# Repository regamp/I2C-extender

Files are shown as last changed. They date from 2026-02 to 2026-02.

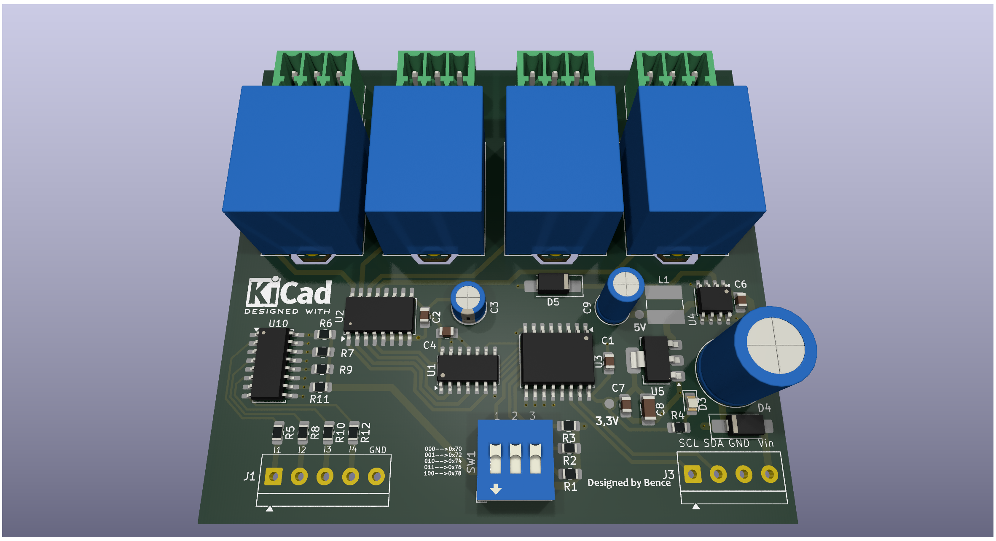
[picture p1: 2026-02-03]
Pictures/I2C_relay_module2.png

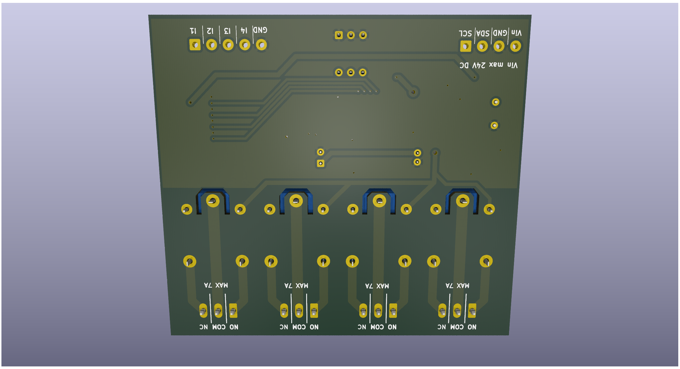
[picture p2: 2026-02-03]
Pictures/I2C_relay_module17.png

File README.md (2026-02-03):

# I2C-extender
I2C bus extender, 4 relay output and 4 input
KiCad 9 project
I2C_relay_module-1
ezgif com-animated-gif-maker
I2C_relay_module

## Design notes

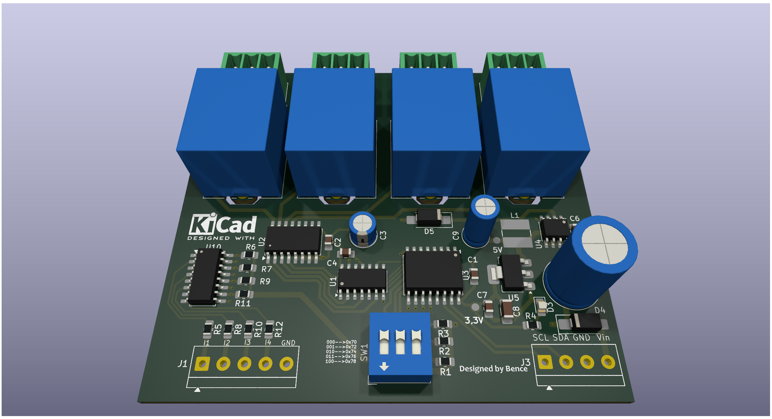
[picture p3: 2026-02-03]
Pictures/I2C_relay_module3.png

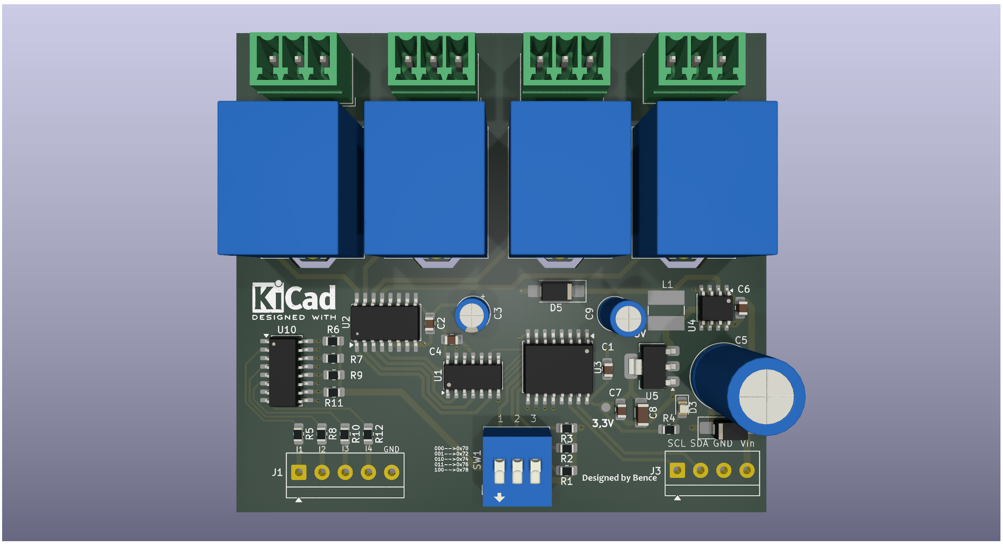
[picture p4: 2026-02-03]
Pictures/I2C_relay_module.png

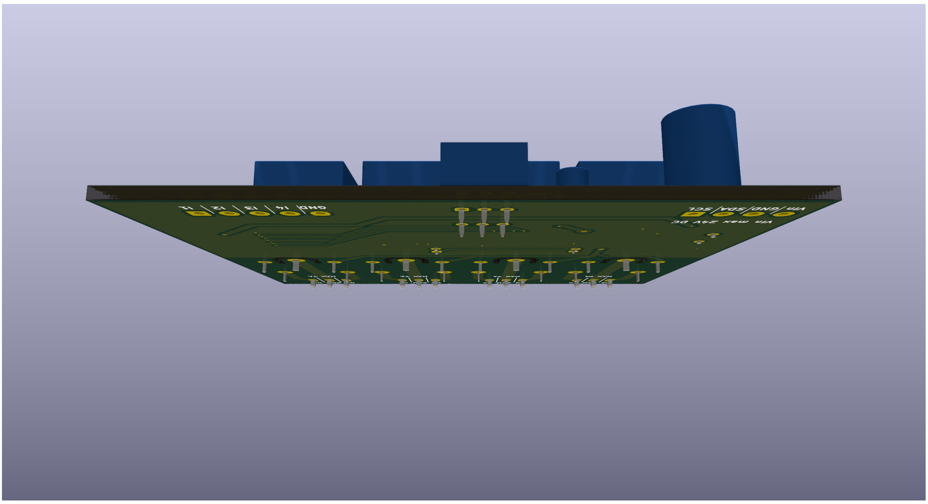
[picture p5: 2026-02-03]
Pictures/I2C_relay_module10.png

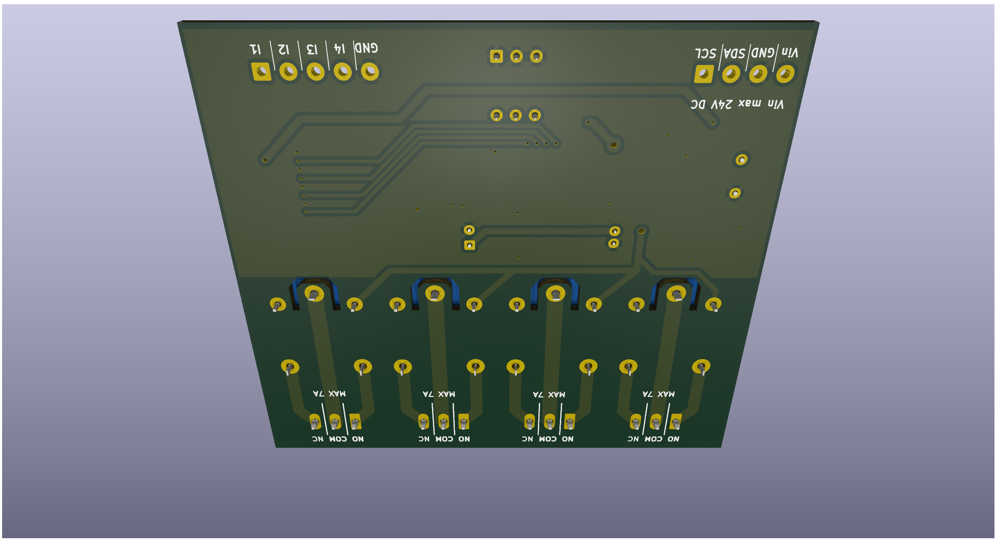
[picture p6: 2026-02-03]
Pictures/I2C_relay_module15.png

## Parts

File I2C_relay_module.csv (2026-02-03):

Id | Designator | Footprint | Quantity | Designation | Supplier and ref
1 | R1,R3,R2,R4 | R_0805_2012Metric_Pad1.20x1.40mm_HandSolder | 4 | 1k
2 | U3 | SOIC-16W_7.5x10.3mm_P1.27mm | 1 | PCF8574T
3 | K3,K4,K1,K2 | Relay_SPDT_SANYOU_SRD_Series_Form_C | 4 | SANYOU_SRD_Form_C
4 | C6,C4,C2,C1,C7 | C_0805_2012Metric_Pad1.18x1.45mm_HandSolder | 5 | 100n
5 | L1 | L_Ferrocore_DLG-0504 | 1 | 68uH
6 | C3 | CP_Radial_D5.0mm_P2.50mm | 1 | 100uF
7 | D3 | LED_0805_2012Metric_Pad1.15x1.40mm_HandSolder | 1 | LED
8 | J3 | TerminalBlock_MetzConnect_Type059_RT06304HBWC_1x04_P3.50mm_Horizontal | 1 | Screw_Terminal_01x04
9 | R6,R10,R12,R5,R9,R7,R8,R11 | R_0805_2012Metric_Pad1.20x1.40mm_HandSolder | 8 | 4k7
10 | D4 | D_SMA_Handsoldering | 1 | MRA4003T3G
11 | J2,J7,J5,J6 | PhoenixContact_MCV_1,5_3-G-3.5_1x03_P3.50mm_Vertical | 4 | Conn_01x03_Socket
12 | C8 | C_1206_3216Metric_Pad1.33x1.80mm_HandSolder | 1 | 10uF
13 | U10 | SOP-16_4.4x10.4mm_P1.27mm | 1 | ELQ3H4
14 | U2 | SOIC-16W_5.3x10.2mm_P1.27mm | 1 | ULN2003A
15 | D5 | D_SMA_Handsoldering | 1 | SS34
16 | J1 | TerminalBlock_MetzConnect_Type059_RT06305HBWC_1x05_P3.50mm_Horizontal | 1 | Screw_Terminal_01x05
17 | C5 | C_Radial_D10.0mm_H16.0mm_P5.00mm | 1 | 470uF
18 | U1 | SOIC-14_3.9x8.7mm_P1.27mm | 1 | 74HCT14
19 | U5 | SOT-223-3_TabPin2 | 1 | LM1117MP-3.3
20 | C9 | C_Radial_D5.0mm_H11.0mm_P2.00mm | 1 | 220uF
21 | U4 | SOIC-8_3.9x4.9mm_P1.27mm | 1 | XL1509-5.0
22 | SW1 | SW_DIP_SPSTx03_Slide_9.78x9.8mm_W7.62mm_P2.54mm | 1 | SW_DIP_x03

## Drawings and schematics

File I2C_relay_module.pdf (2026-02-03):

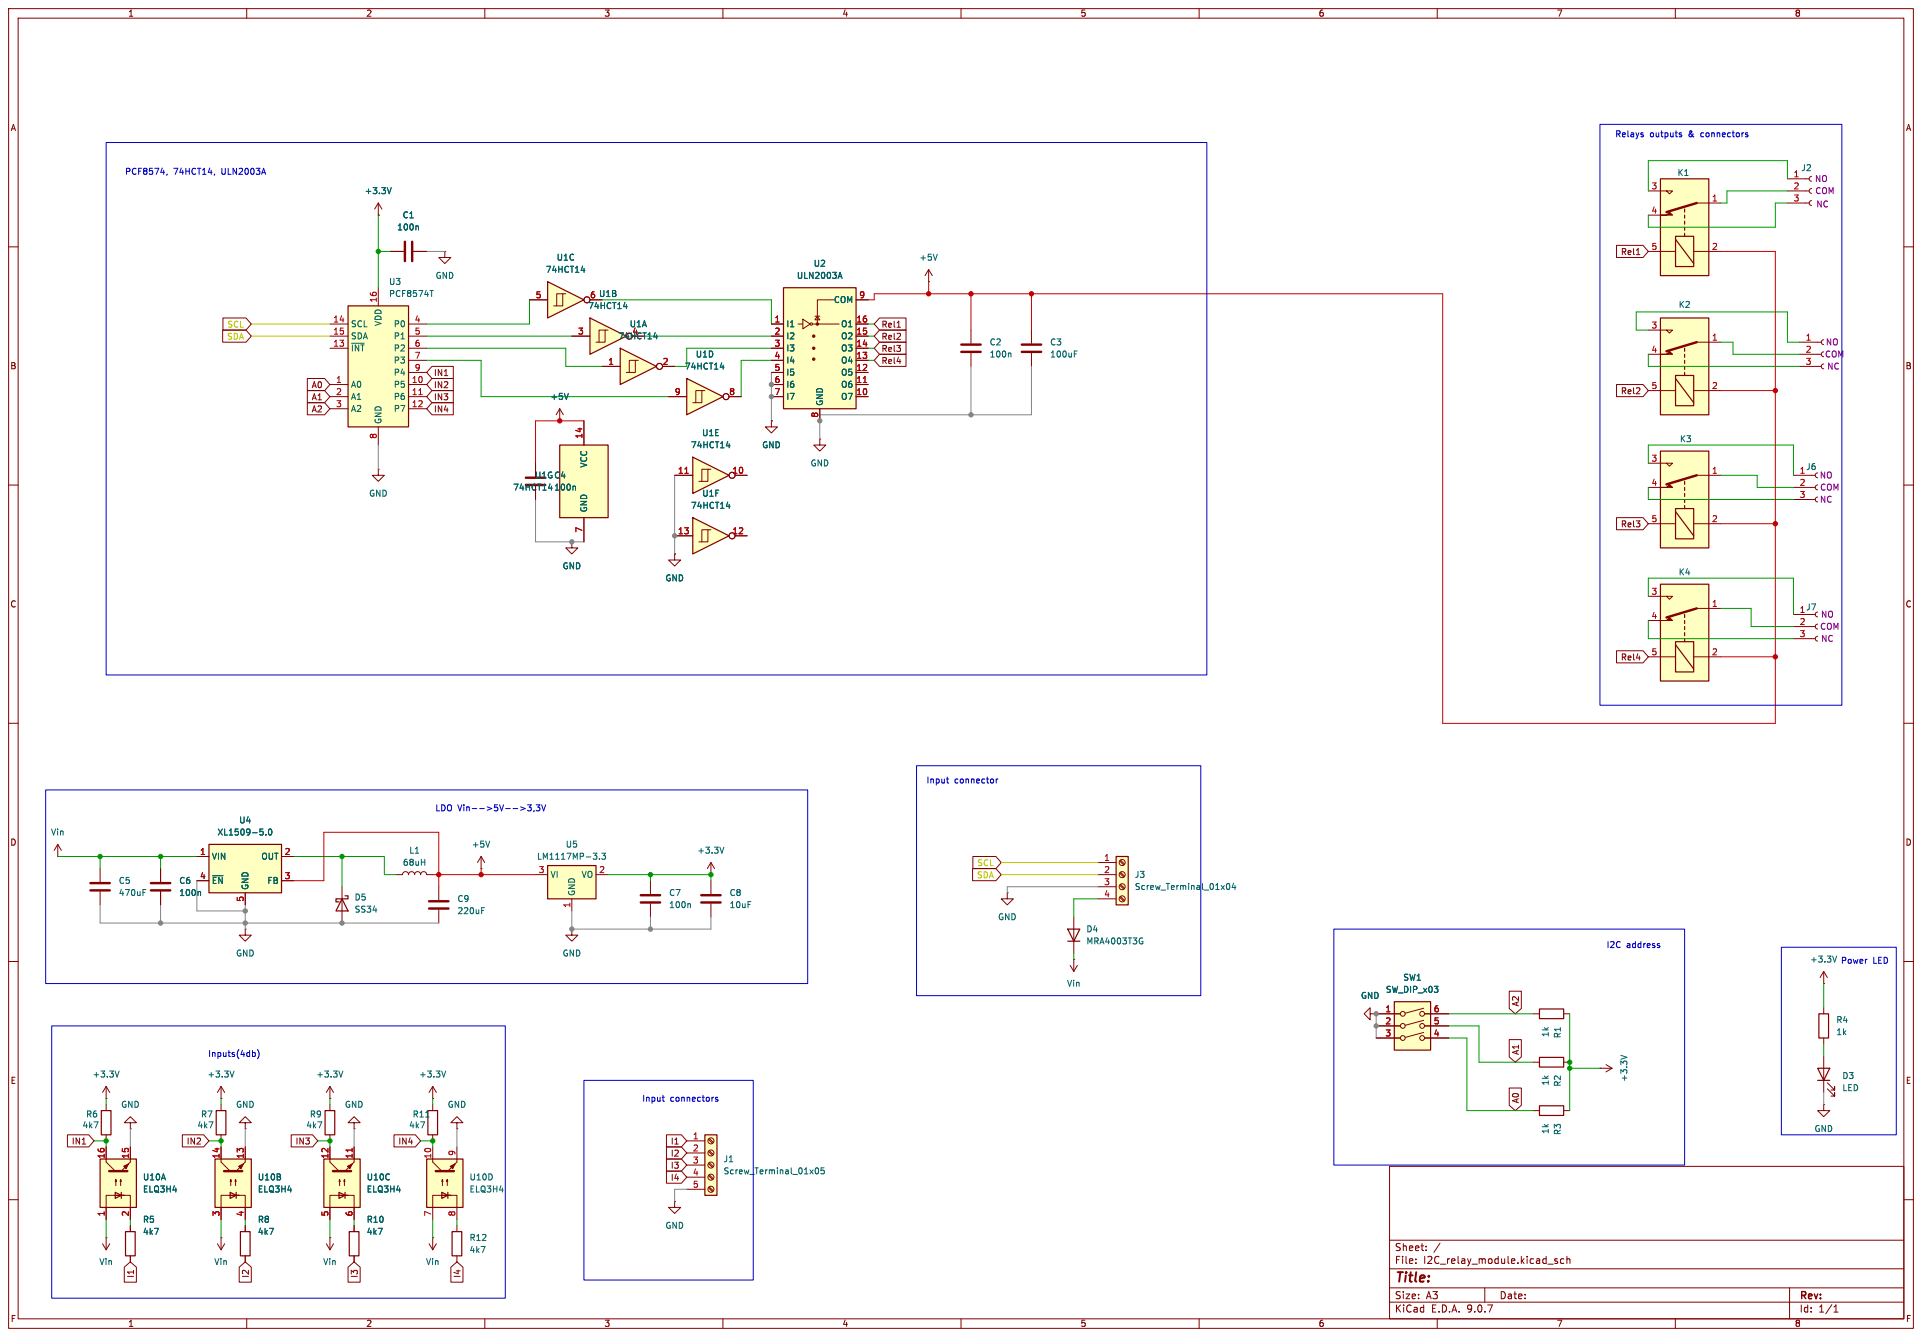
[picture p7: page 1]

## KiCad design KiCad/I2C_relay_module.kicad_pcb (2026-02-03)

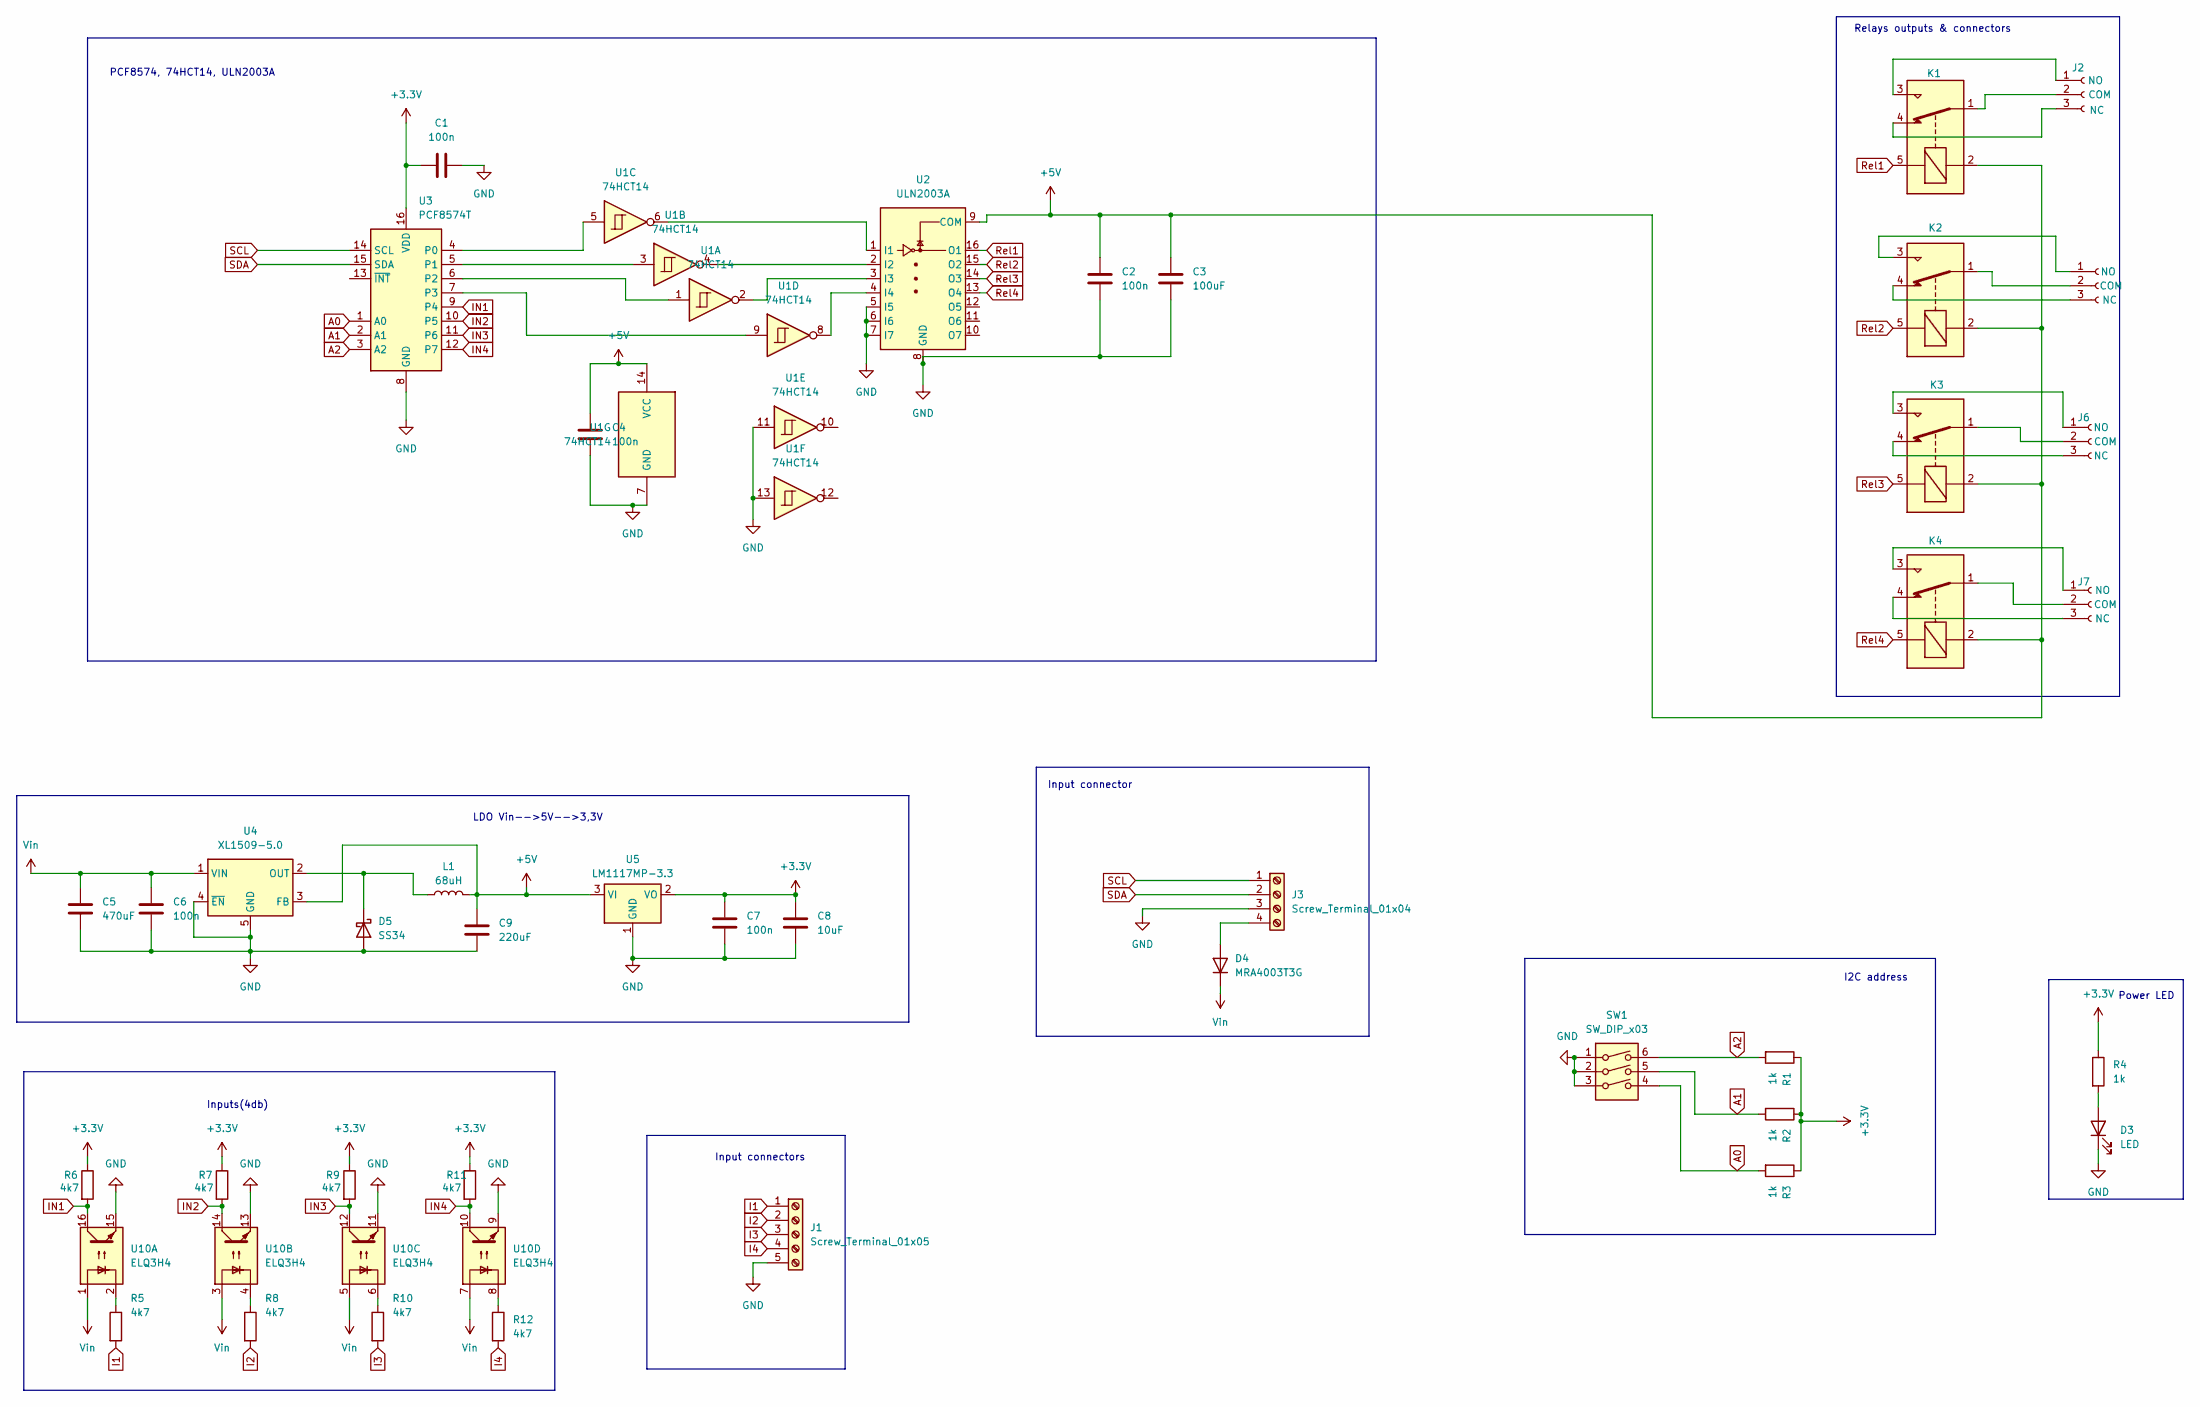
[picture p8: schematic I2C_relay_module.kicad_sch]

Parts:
C1, C2, C4, C6, C7: 100n; C_0805_2012Metric_Pad1.18x1.45mm_HandSolder
C3: 100uF; CP_Radial_D5.0mm_P2.50mm
C5: 470uF; C_Radial_D10.0mm_H16.0mm_P5.00mm
C8: 10uF; C_1206_3216Metric_Pad1.33x1.80mm_HandSolder
C9: 220uF; C_Radial_D5.0mm_H11.0mm_P2.00mm
D3: LED; LED_0805_2012Metric_Pad1.15x1.40mm_HandSolder
D4: MRA4003T3G; D_SMA_Handsoldering
D5: SS34; D_SMA_Handsoldering
J1: Screw_Terminal_01x05; TerminalBlock_MetzConnect_Type059_RT06305HBWC_1x05_P3.50mm_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
J2, J5, J6, J7: Conn_01x03_Socket; PhoenixContact_MCV_1,5_3-G-3.5_1x03_P3.50mm_Vertical
J3: Screw_Terminal_01x04; TerminalBlock_MetzConnect_Type059_RT06304HBWC_1x04_P3.50mm_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
K1, K2, K3, K4: SANYOU_SRD_Form_C; Relay_SPDT_SANYOU_SRD_Series_Form_C
L1: 68uH; L_Ferrocore_DLG-0504
R1, R2, R3, R4: 1k; R_0805_2012Metric_Pad1.20x1.40mm_HandSolder
R5, R6, R7, R8, R9, R10, R11, R12: 4k7; R_0805_2012Metric_Pad1.20x1.40mm_HandSolder
SW1: SW_DIP_x03; SW_DIP_SPSTx03_Slide_9.78x9.8mm_W7.62mm_P2.54mm
U1: 74HCT14; SOIC-14_3.9x8.7mm_P1.27mm
U2: ULN2003A; SOIC-16W_5.3x10.2mm_P1.27mm
U3: PCF8574T; SOIC-16W_7.5x10.3mm_P1.27mm
U4: XL1509-5.0; SOIC-8_3.9x4.9mm_P1.27mm
U5: LM1117MP-3.3; SOT-223-3_TabPin2
U10: ELQ3H4; SOP-16_4.4x10.4mm_P1.27mm

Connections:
+3.3V: C1.1, C7.2, C8.1, R1.1, R2.1, R3.1, R4.1, R6.1, R7.1, R9.1, R11.1, U3.16 (VDD), U5.2 (VO)
+5V: C2.1, C3.1, C4.2, C9.1, K1.2, K2.2, K3.2, K4.2, L1.2, U1.14 (VCC), U2.9 (COM), U4.3 (FB), U5.3 (VI)
A0: R3.2, SW1.4, U3.1 (A0)
A1: R2.2, SW1.5, U3.2 (A1)
A2: R1.2, SW1.6, U3.3 (A2)
GND: C1.2, C2.2, C3.2, C4.1, C5.2, C6.1, C7.1, C8.2, C9.2, D3.1 (K), D5.2 (A), J1.5, J3.3, SW1.1, SW1.2, SW1.3, U1.7 (GND), U1.11, U1.13, U2.5 (I5), U2.6 (I6), U2.7 (I7), U2.8 (GND), U3.8 (GND), U4.4 (~EN), U4.5 (GND), U4.6 (GND), U4.7 (GND), U4.8 (GND), U5.1 (GND), U10.9, U10.11, U10.13, U10.15
I1: J1.1, R5.2
I2: J1.2, R8.2
I3: J1.3, R10.2
I4: J1.4, R12.2
IN1: R6.2, U3.9 (P4), U10.16
IN2: R7.2, U3.10 (P5), U10.14
IN3: R9.2, U3.11 (P6), U10.12
IN4: R11.2, U3.12 (P7), U10.10
unnamed: D3.2 (A), R4.2
unnamed: D4.2 (A), J3.4
unnamed: D5.1 (K), L1.1, U4.2 (OUT)
unnamed: J2.1, K1.3
unnamed: J2.2, K1.1
unnamed: J2.3, K1.4
unnamed: J5.1, K2.3
unnamed: J5.2, K2.1
unnamed: J5.3, K2.4
unnamed: J6.1, K3.3
unnamed: J6.2, K3.1
unnamed: J6.3, K3.4
unnamed: J7.1, K4.3
unnamed: J7.2, K4.1
unnamed: J7.3, K4.4
unnamed: R5.1, U10.2
unnamed: R8.1, U10.4
unnamed: R10.1, U10.6
unnamed: R12.1, U10.8
unnamed: U1.6, U2.1 (I1)
unnamed: U1.4, U2.2 (I2)
unnamed: U1.2, U2.3 (I3)
unnamed: U1.8, U2.4 (I4)
unnamed: U1.5, U3.4 (P0)
unnamed: U1.3, U3.5 (P1)
unnamed: U1.1, U3.6 (P2)
unnamed: U1.9, U3.7 (P3)
Rel1: K1.5, U2.16 (O1)
Rel2: K2.5, U2.15 (O2)
Rel3: K3.5, U2.14 (O3)
Rel4: K4.5, U2.13 (O4)
SCL: J3.1, U3.14 (SCL)
SDA: J3.2, U3.15 (SDA)
Vin: C5.1, C6.2, D4.1 (K), U4.1 (VIN), U10.1, U10.3, U10.5, U10.7

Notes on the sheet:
Input connectors
Power LED
I2C address
Input connector
Inputs(4db)
Relays outputs & connectors
PCF8574, 74HCT14, ULN2003A
LDO Vin-->5V-->3,3V

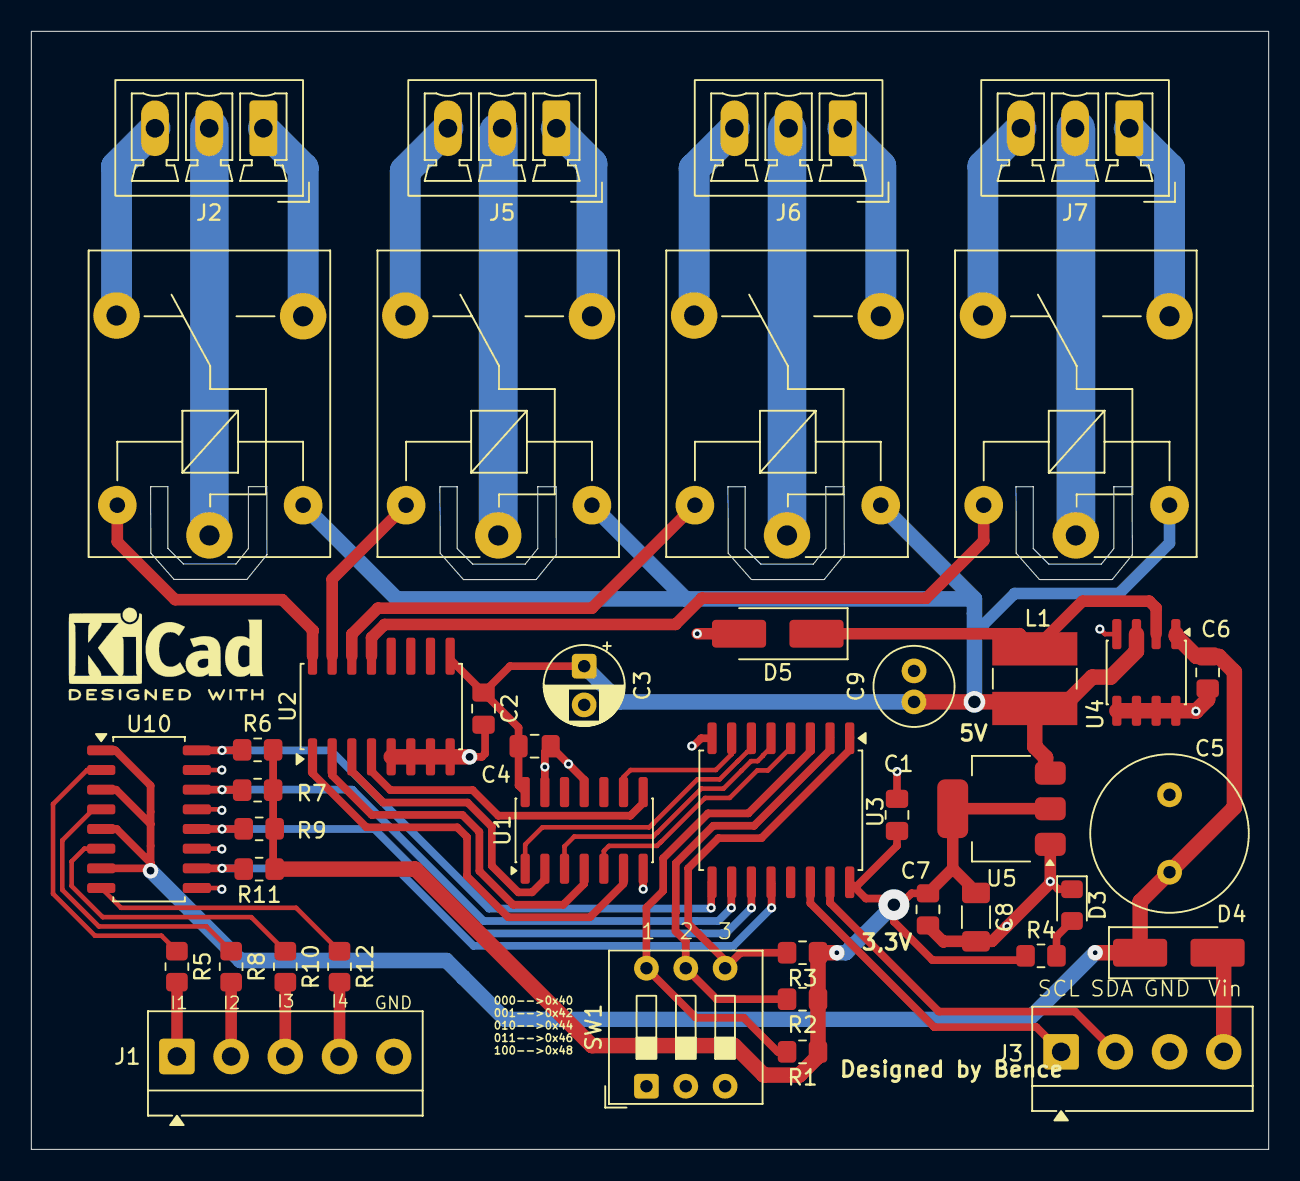
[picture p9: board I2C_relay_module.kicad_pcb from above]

Board: 2 copper layers, 79.9 x 72.2 mm, 42 parts (0 on the bottom side), 48 nets.
